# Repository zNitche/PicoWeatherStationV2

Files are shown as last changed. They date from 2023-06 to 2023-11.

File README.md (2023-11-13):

## PicoWeatherStationV2

Off-grid, standalone version of [PicoWeatherStation](https://github.com/zNitche/PicoWeatherStation) powered
by [strawberryAPI](https://github.com/zNitche/strawberryAPI).

---

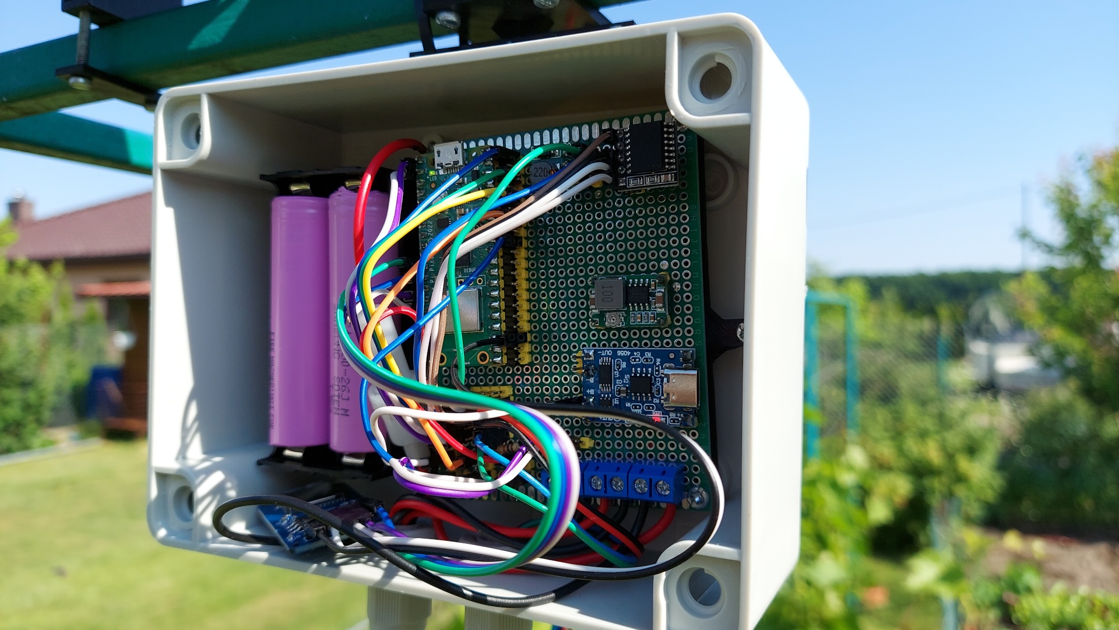
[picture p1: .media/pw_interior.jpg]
interior

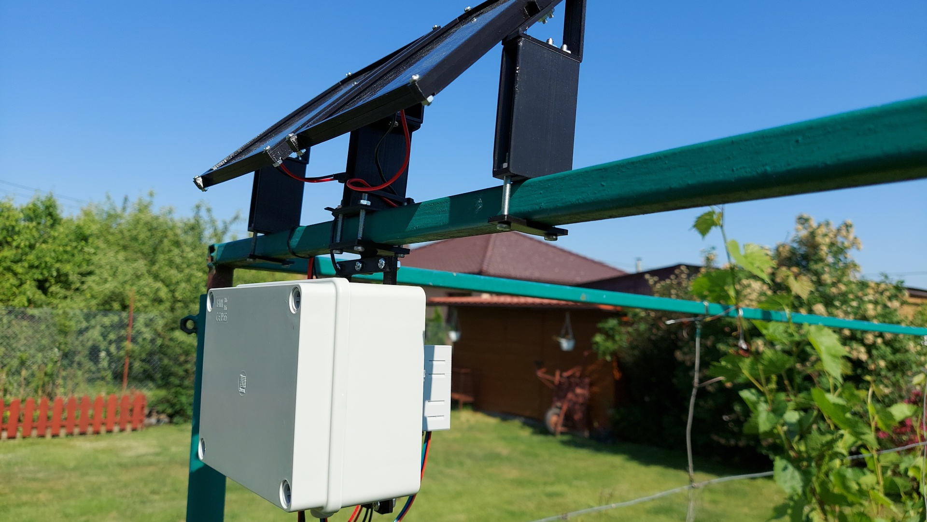
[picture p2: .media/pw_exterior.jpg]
exterior


#### Features

- Logging temperature & humidity.
- Logging battery & pv voltage.
- Access to logged data through WiFi hotspot and web app.
- Logs visualisation using `chart.js`.

#### Setup

1. clone repo
2. clone submodules

```
git submodule update --init --recursive
```

3. set `HOTSPOT_SSID` and `HOTSPOT_PASSWORD` in `config.py`
4. set `WEATHER_LOGS_PER_HOUR` in `config.py` (default logging sensors data every 20 minutes).
5. format sd card (FAT32).
6. `chart.js` setup:
   rpi pico doesn't have enough space for flashing css/js libs, get `chart.js` from
   cdns (`https://cdn.jsdelivr.net/npm/chart.js@4.3.0/dist/chart.umd.min.js`),
   then put it on sd card `/static/libs/chart.js`.
7. flash `RPi Pico`.

#### Wiring

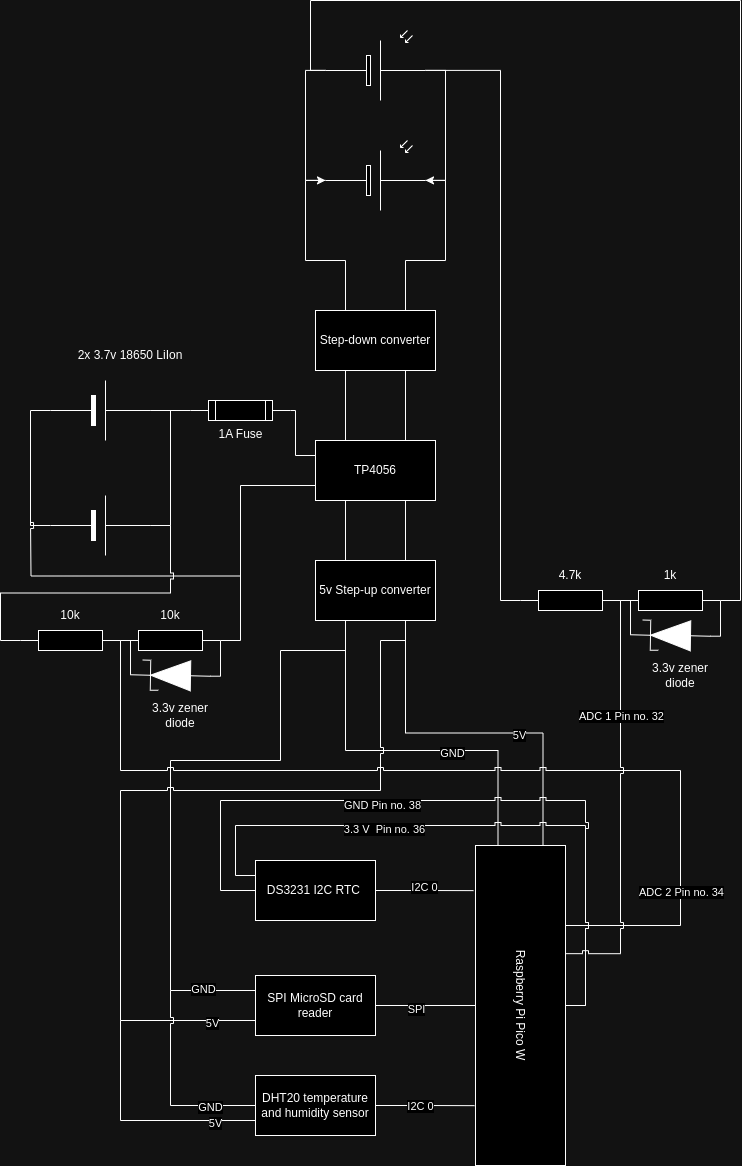
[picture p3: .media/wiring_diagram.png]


#### Parts

| Part Name | Quantity |
|---|:---:|
| Raspberry Pi Pico W | 1 |
| DHT20 temperature and humidity sensor  | 1 |
| DS3231 I2C RTC module | 1 |
| MicroSD card | 1 |
| SPI MicroSD card reader module | 1 |
| Circuit board (70x90mm) | 1 |
| Waterproof case | 1 |
| Gold pin connectors | ? |
| Connecting wires | ? |
| Cell holder for 2x 18650 battery | 1 |
| 18650 li-ion battery | 2 |
| Step-down Voltage Regulator - 1,0V-17V | 1 |
| Step-up converter 5V | 1 |
| TP4056 1S 3,7V with protection | 1 |
| 6V solar panel 165x135x3mm | 2 |
| 1A fuse with wires | 1 |
| 3.3V zener diode | 2 |
| 4.7k resistor | 1 |
| 1k resistor | 1 |
| 10k resistor | 2 |
| ARK connector raster 5.0mm 2 pin | 3 |
| 3mm screws and nuts | ? |
| 4mm screws and nuts | ? |

#### 3D printed parts

all models are provided in `freecad` project files for easier modifications.

| Part Name | Quantity |
|---|:---:|
| bat_mount | 1 |
| case_backplate | 1 |
| case_bridge | 2 |
| case_m_top | 1 |
| case_th_connector | 1 |
| pcb_mount | 1 |
| pv_b_holder | 2 |
| pv_b_s_mount | 2 |
| pv_t_mount | 1 |
| pv_s_mount | 2 |
| pv_t_s_mount | 2 |
| th_holder | 1 |
| th_holder_b | 1 |
| th_holder_mount | 1 |

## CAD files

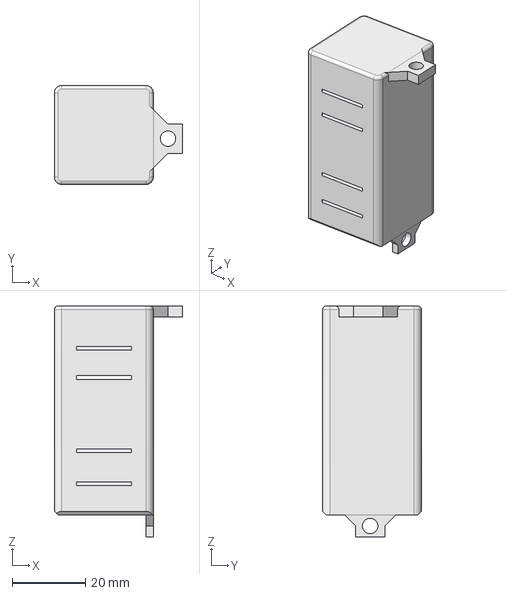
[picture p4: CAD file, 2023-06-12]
.models/th_holder.FCStd
35.0 x 27.0 x 63.0 mm

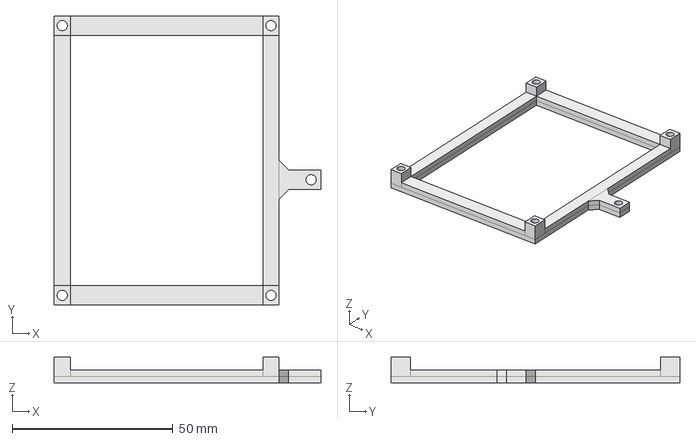
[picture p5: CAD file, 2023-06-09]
.models/pcb_mount.FCStd
83.0 x 90.0 x 8.00 mm

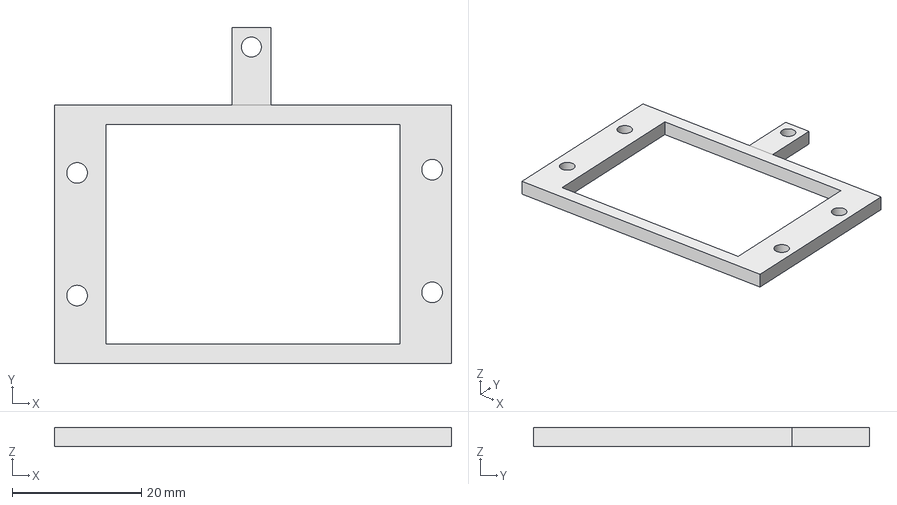
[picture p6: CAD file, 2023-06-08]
.models/bat_mount.FCStd
61.5 x 52.0 x 3.00 mm

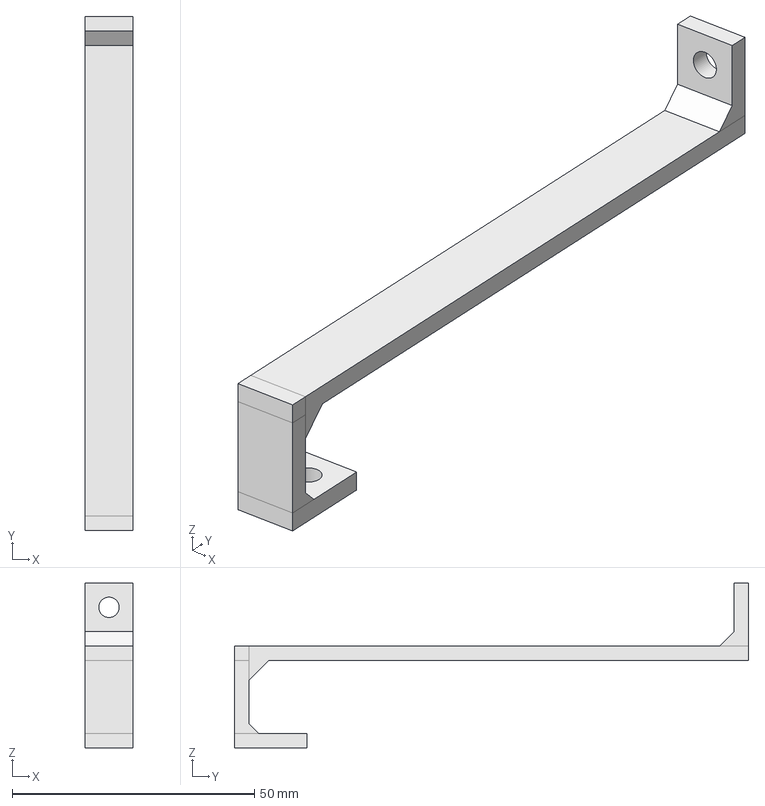
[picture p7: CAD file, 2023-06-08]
.models/case_th_connector.FCStd
10.0 x 106.0 x 34.0 mm

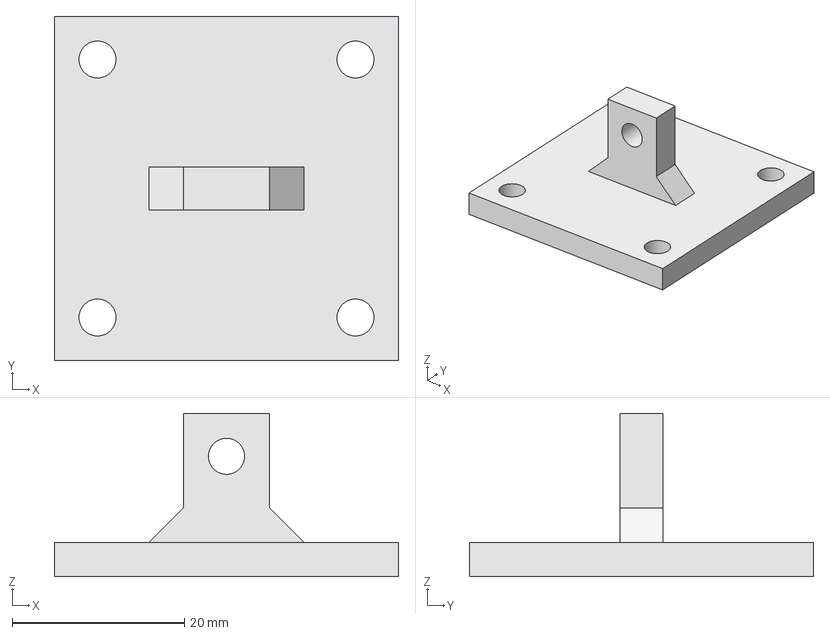
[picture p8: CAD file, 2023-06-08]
.models/case_m_top.FCStd
40.0 x 40.0 x 19.0 mm

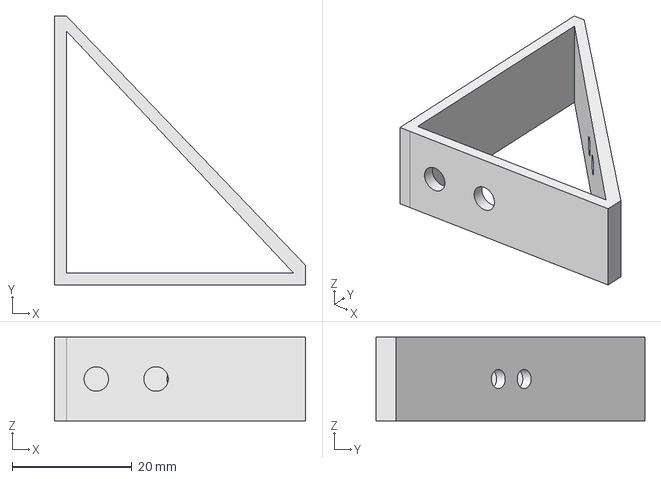
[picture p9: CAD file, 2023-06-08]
.models/pv_t_s_mount.FCStd
42.0 x 45.0 x 14.0 mm

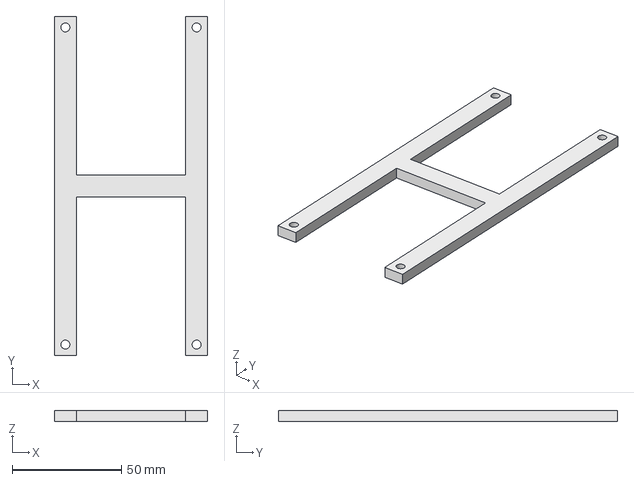
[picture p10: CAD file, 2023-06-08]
.models/case_backplate.FCStd
70.0 x 155.0 x 5.00 mm

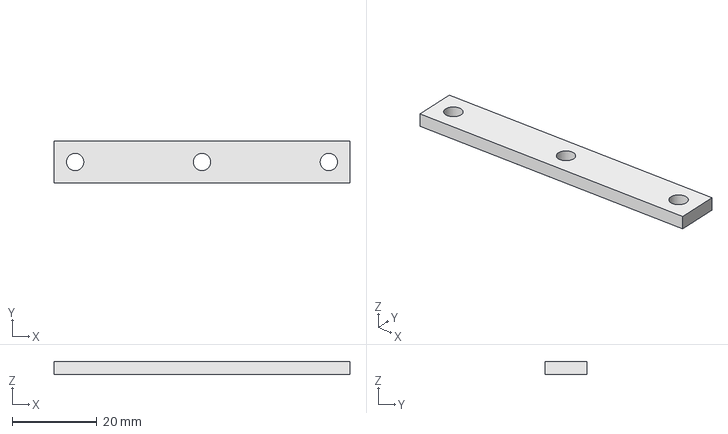
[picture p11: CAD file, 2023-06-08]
.models/case_bridge.FCStd
70.0 x 10.0 x 3.00 mm

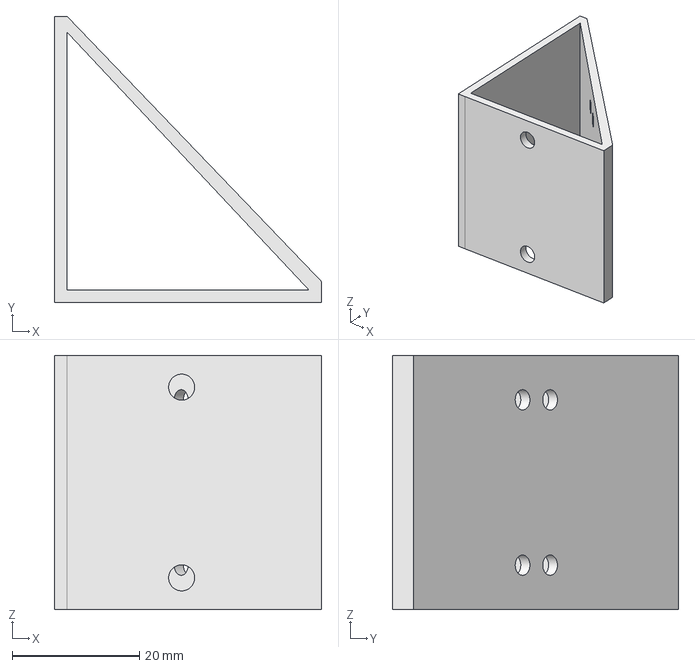
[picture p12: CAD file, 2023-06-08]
.models/pv_t_mount.FCStd
42.0 x 45.0 x 40.0 mm

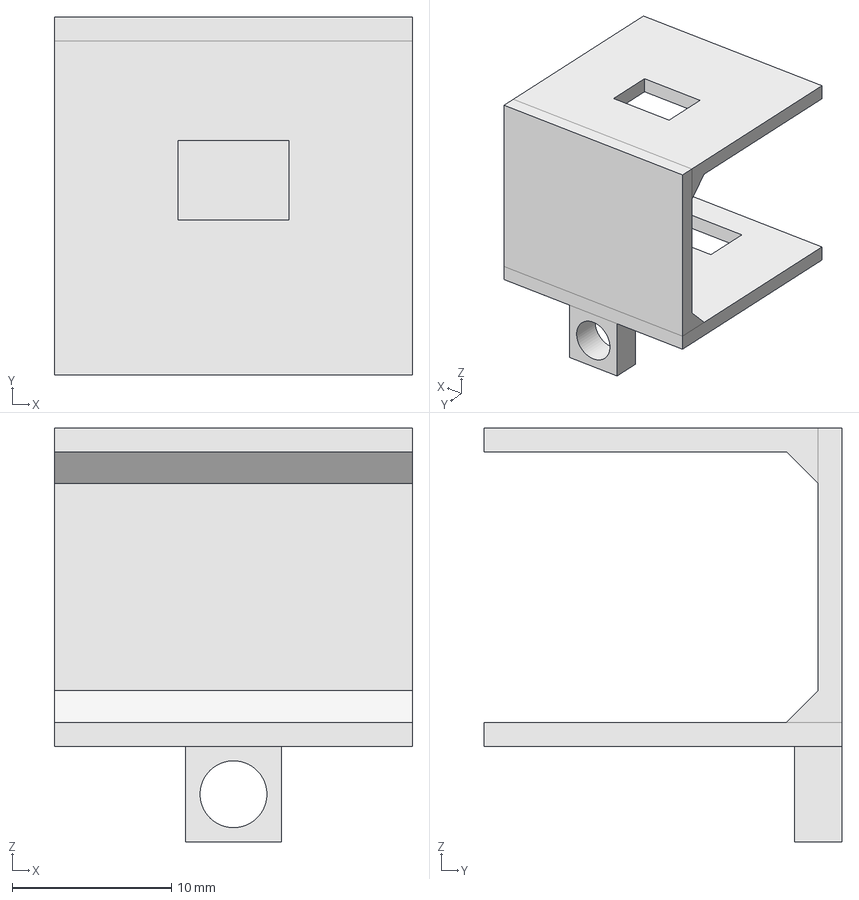
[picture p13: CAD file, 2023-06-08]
.models/th_holder_b.FCStd
22.5 x 22.5 x 26.0 mm

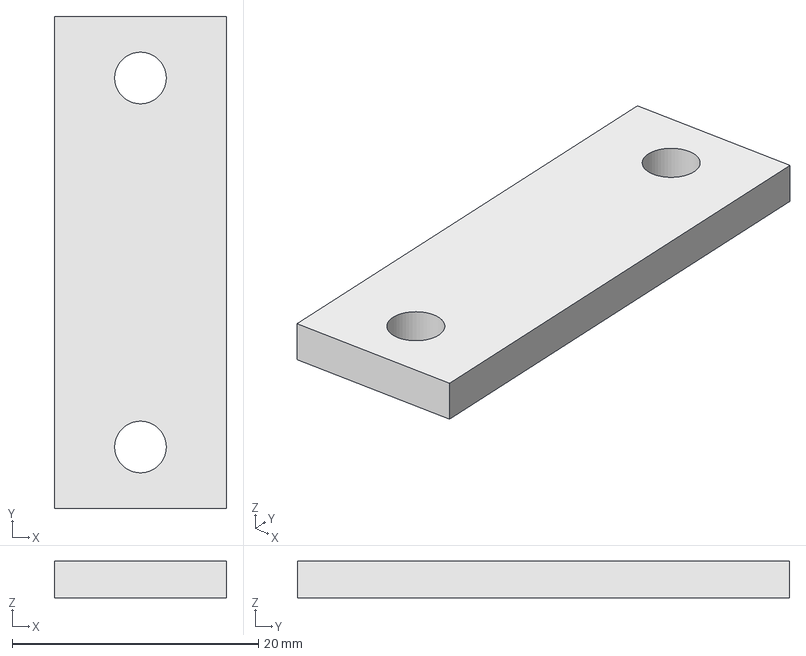
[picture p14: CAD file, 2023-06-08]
.models/pv_b_s_mount.FCStd
14.0 x 40.0 x 3.00 mm

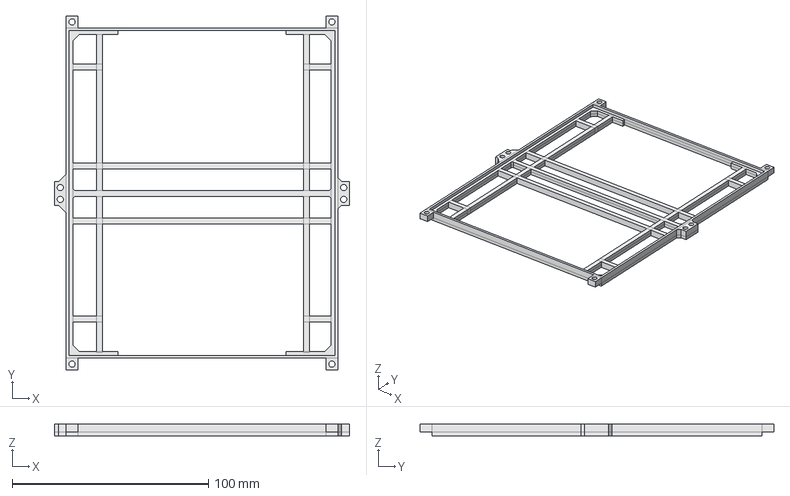
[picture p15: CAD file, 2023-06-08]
.models/pv_b_holder.FCStd
150.5 x 180.5 x 6.00 mm

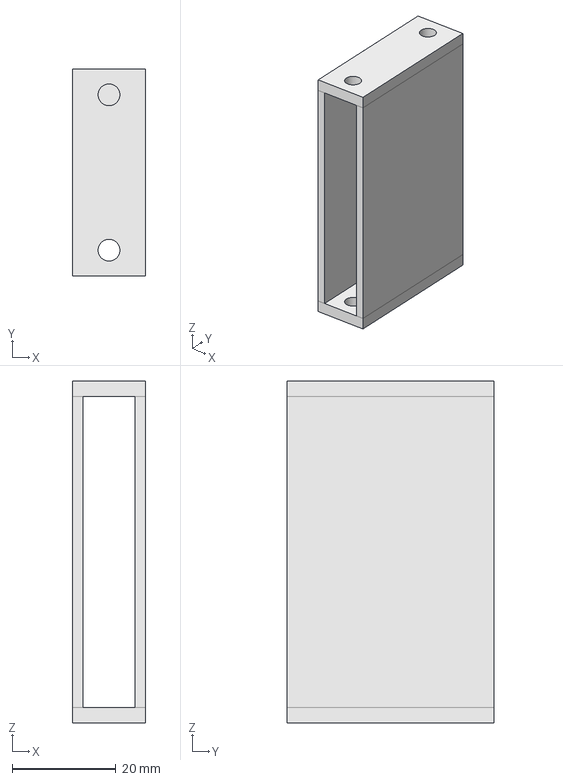
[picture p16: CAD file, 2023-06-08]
.models/pv_s_mount.FCStd
14.0 x 40.0 x 66.0 mm

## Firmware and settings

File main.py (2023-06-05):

from strawberry.controllers.server import Server
from pico_weather_v2.config import Config
from pico_weather_v2.app import create_app
from libs import sdcard
import machine
import uos


def mount_sd_card():
    cs = machine.Pin(9, machine.Pin.OUT)
    spi = machine.SPI(1, baudrate=1000000,
                      polarity=0, phase=0,
                      bits=8, firstbit=machine.SPI.MSB,
                      sck=machine.Pin(10), mosi=machine.Pin(11), miso=machine.Pin(8))

    card = sdcard.SDCard(spi, cs)
    vfs = uos.VfsFat(card)
    uos.mount(vfs, Config.SD_CARD_MOUNT_DIR)


def main():
    mount_sd_card()

    server = Server(hotspot_mode=True,
                    hotspot_name=Config.HOTSPOT_SSID, hotspot_password=Config.HOTSPOT_PASSWORD,
                    debug_mode=Config.DEBUG)

    server.set_app(create_app())
    server.run()

    server.app.weather_logger.init_timer(periodic=True, period=Config.WEATHER_LOGGER_TIMER_PERIOD)

    server.run_mainloop()


if __name__ == "__main__":
    main()

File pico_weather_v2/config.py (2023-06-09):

class Config:
    DEBUG = False

    HOTSPOT_SSID = "pw_1"
    HOTSPOT_PASSWORD = "123456789"

    SD_CARD_MOUNT_DIR = "/sd"

    ADC_CONVERSION_FACTOR = 3.3 / 65535
    PV_VOLTAGE_DIVIDER_FACTOR = 6  # 1V ON ADC PIN = 6V OF SOURCE VOLTAGE
    BAT_VOLTAGE_DIVIDER_FACTOR = 2  # 1V ON ADC PIN = 2V OF SOURCE VOLTAGE

    SENSORS_ACCURACY = 1

    WEATHER_LOGS_DIR_PATH = f"{SD_CARD_MOUNT_DIR}/weather_logs"
    WEATHER_LOGGER_TIMER_PERIOD = 30000
    WEATHER_LOGS_PER_HOUR = 3

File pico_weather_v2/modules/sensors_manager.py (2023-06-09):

from libs.aht20 import AHT20
from libs.ds3231 import DS3231
from pico_weather_v2.config import Config
import machine


class SensorsManager:
    def __init__(self, i2c, logs_dir_path=None):
        self.i2c = i2c

        self.logs_dir_path = logs_dir_path

        self.aht20 = AHT20(self.i2c)
        self.rtc = DS3231(self.i2c)

        self.bat_adc = machine.ADC(28)
        self.pv_adc = machine.ADC(27)

    def get_voltage_from_adc(self, adc, voltage_divider_factor):
        adc_value = adc.read_u16()
        adc_voltage = adc_value * Config.ADC_CONVERSION_FACTOR

        voltage = adc_voltage * voltage_divider_factor
        voltage = voltage if voltage >= 0 else 0

        return round(voltage, Config.SENSORS_ACCURACY)

    def get_battery_voltage(self):
        return self.get_voltage_from_adc(self.bat_adc, Config.BAT_VOLTAGE_DIVIDER_FACTOR)

    def get_pv_voltage(self):
        return self.get_voltage_from_adc(self.pv_adc, Config.PV_VOLTAGE_DIVIDER_FACTOR)

    def get_temp_and_humidity(self):
        temp = round(self.aht20.get_temperature(), Config.SENSORS_ACCURACY)
        humi = round(self.aht20.get_relative_humidity(), Config.SENSORS_ACCURACY)

        return temp, humi

    def get_datetime(self):
        return self.rtc.get_datetime()

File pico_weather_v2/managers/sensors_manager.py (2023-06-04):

from libs.aht20 import AHT20
from libs.ds3231 import DS3231
from pico_weather_v2.config import Config
from pico_weather_v2 import utils
import machine
import uos


class SensorsManager:
    def __init__(self, i2c, logs_dir_path=None):
        self.i2c = i2c
        self.logs_timer = machine.Timer()

        self.logs_dir_path = logs_dir_path

        self.aht20 = AHT20(self.i2c)
        self.rtc = DS3231(self.i2c)

        self.bat_adc = machine.ADC(28)
        self.pv_adc = machine.ADC(27)

    def init_logs_timer(self):
        if not utils.check_if_exists(self.logs_dir_path):
            uos.mkdir(self.logs_dir_path)

        self.logs_timer.init(period=2000, mode=machine.Timer.PERIODIC, callback=lambda t: self.log_sensors_data())

    def get_voltage_from_adc(self, adc):
        adc_value = adc.read_u16()
        adc_voltage = adc_value * Config.ADC_CONVERSION_FACTOR

        return adc_voltage * Config.VOLTAGE_DIVIDER_FACTOR - Config.ADC_ACCURACY

    def get_battery_voltage(self):
        return self.get_voltage_from_adc(self.bat_adc)

    def get_pv_voltage(self):
        return self.get_voltage_from_adc(self.pv_adc)

    def get_temp_and_humidity(self):
        temp = self.aht20.get_temperature()
        humi = self.aht20.get_relative_humidity()

        return temp, humi

    def get_datetime(self):
        return self.rtc.get_datetime()

    def get_log_row(self):
        temp, humi = self.get_temp_and_humidity()
        bat_volt = self.get_battery_voltage()
        pv_volt = self.get_pv_voltage()
        datetime = self.get_datetime().to_iso_string()

        row = f"{datetime},{temp},{humi},{bat_volt},{pv_volt}"

        return row

    def log_sensors_data(self):
        if self.logs_dir_path:
            day_date = self.get_datetime().to_iso_string().split("T")[0]
            log_path = f"{self.logs_dir_path}/{day_date}.txt"

            with open(log_path, "a+") as logs_file:
                logs_file.write(self.get_log_row() + "\n")

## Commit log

2023-06-04 sensors manager + sd card setup
2023-06-04 adc voltmeters
2023-06-04 synced ds3231 driver
2023-06-04 bootstrap & chart.js setup + sensors tweaks
2023-06-04 basic sensors logging system
2023-06-05 added weather logger for saving sensors data
2023-06-06 updated ds3231 driver
2023-06-06 api for getting sensors and logs data
2023-06-07 added config entry for setting sensors reading accuracy
2023-06-07 styling + chart.js powered graphs for log page
2023-06-08 added models for 3d printing
    [bat_mount.FCStd, case_backplate.FCStd, case_bridge.FCStd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]
2023-06-09 updated pcb mount model
    [pcb_mount.FCStd]
2023-06-09 changed battery voltage divider to 1/2 ratio (instead of 1/6)
2023-06-10 added management site for performing machine hard reset
    [routes.py]
2023-06-10 removed checking if sensors log is being performed
2023-06-12 updated temp sensor housing 3d model
    [th_holder.FCStd]
2023-11-13 added wiring diagram
